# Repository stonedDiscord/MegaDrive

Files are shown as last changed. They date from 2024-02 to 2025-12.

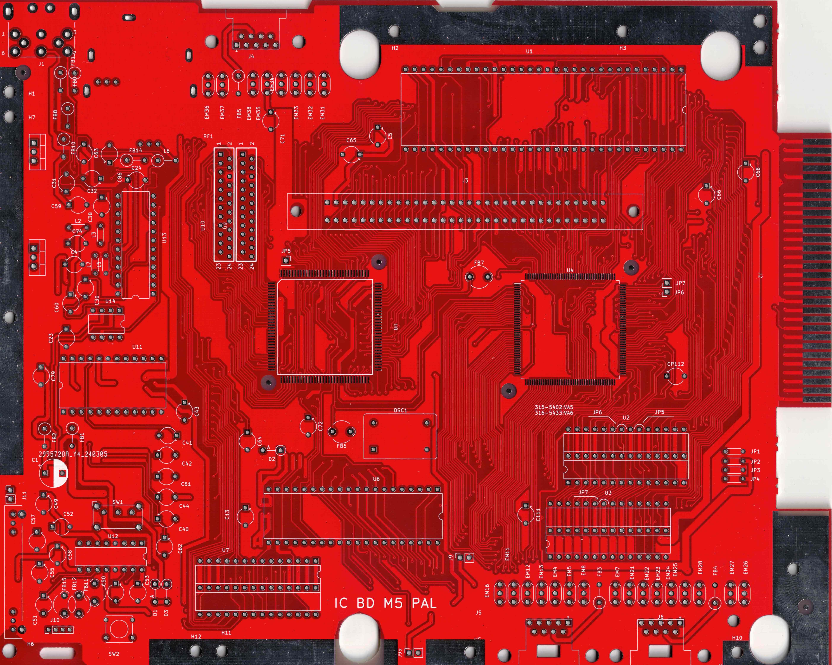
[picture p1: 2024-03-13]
scan.jpg

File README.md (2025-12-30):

# MegaDrive
An Open-Source HardWare (OSHW) recreation of the Sega Mega Drive

The design tries to be a 1:1 recreation of the original IC BD M5 PAL board.

## Some of the planned Changes and improvements
- [ ] Verify component values
- [ ] S-Video out

## Tips if you decide to make this/get it made
The dimensions are 240x191mm.

You will have to source the 2 SEGA custom chips from either a dead board or a chip dealer.

## Roadmap:
Look at the changes in the other revisions.

## Inspired by
https://github.com/Redherring32/OpenTendo

## Credits

ArcadeTV for the stripped scans:
https://circuit-board.de/forum/index.php/Thread/13913-STRIP-CLUB-PCB-Scans/

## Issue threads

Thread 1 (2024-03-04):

Holes

stonedDiscord, 2024-03-04:
I got this email from the board house

Hello,

Sorry to bother you, but there is an issue that we want to confirm with you before proceeding.

The drill holes and circles in KO layer are overlapped at the arrow in greber file, shall we proceed them as per drill layer or KO layer?

Looks like the cartridge port footprint is wrong, need to fix that.

danboid, 2025-09-05:
Hi @stonedDiscord

Did you get around to fixing that footprint?

stonedDiscord, 2025-09-05:
The board ended up being fine

stonedDiscord, 2025-09-05:
The issue was fixed in 286d83944ec59dee92658831e7c67fdc743904b5

Closed 2025-09-05.

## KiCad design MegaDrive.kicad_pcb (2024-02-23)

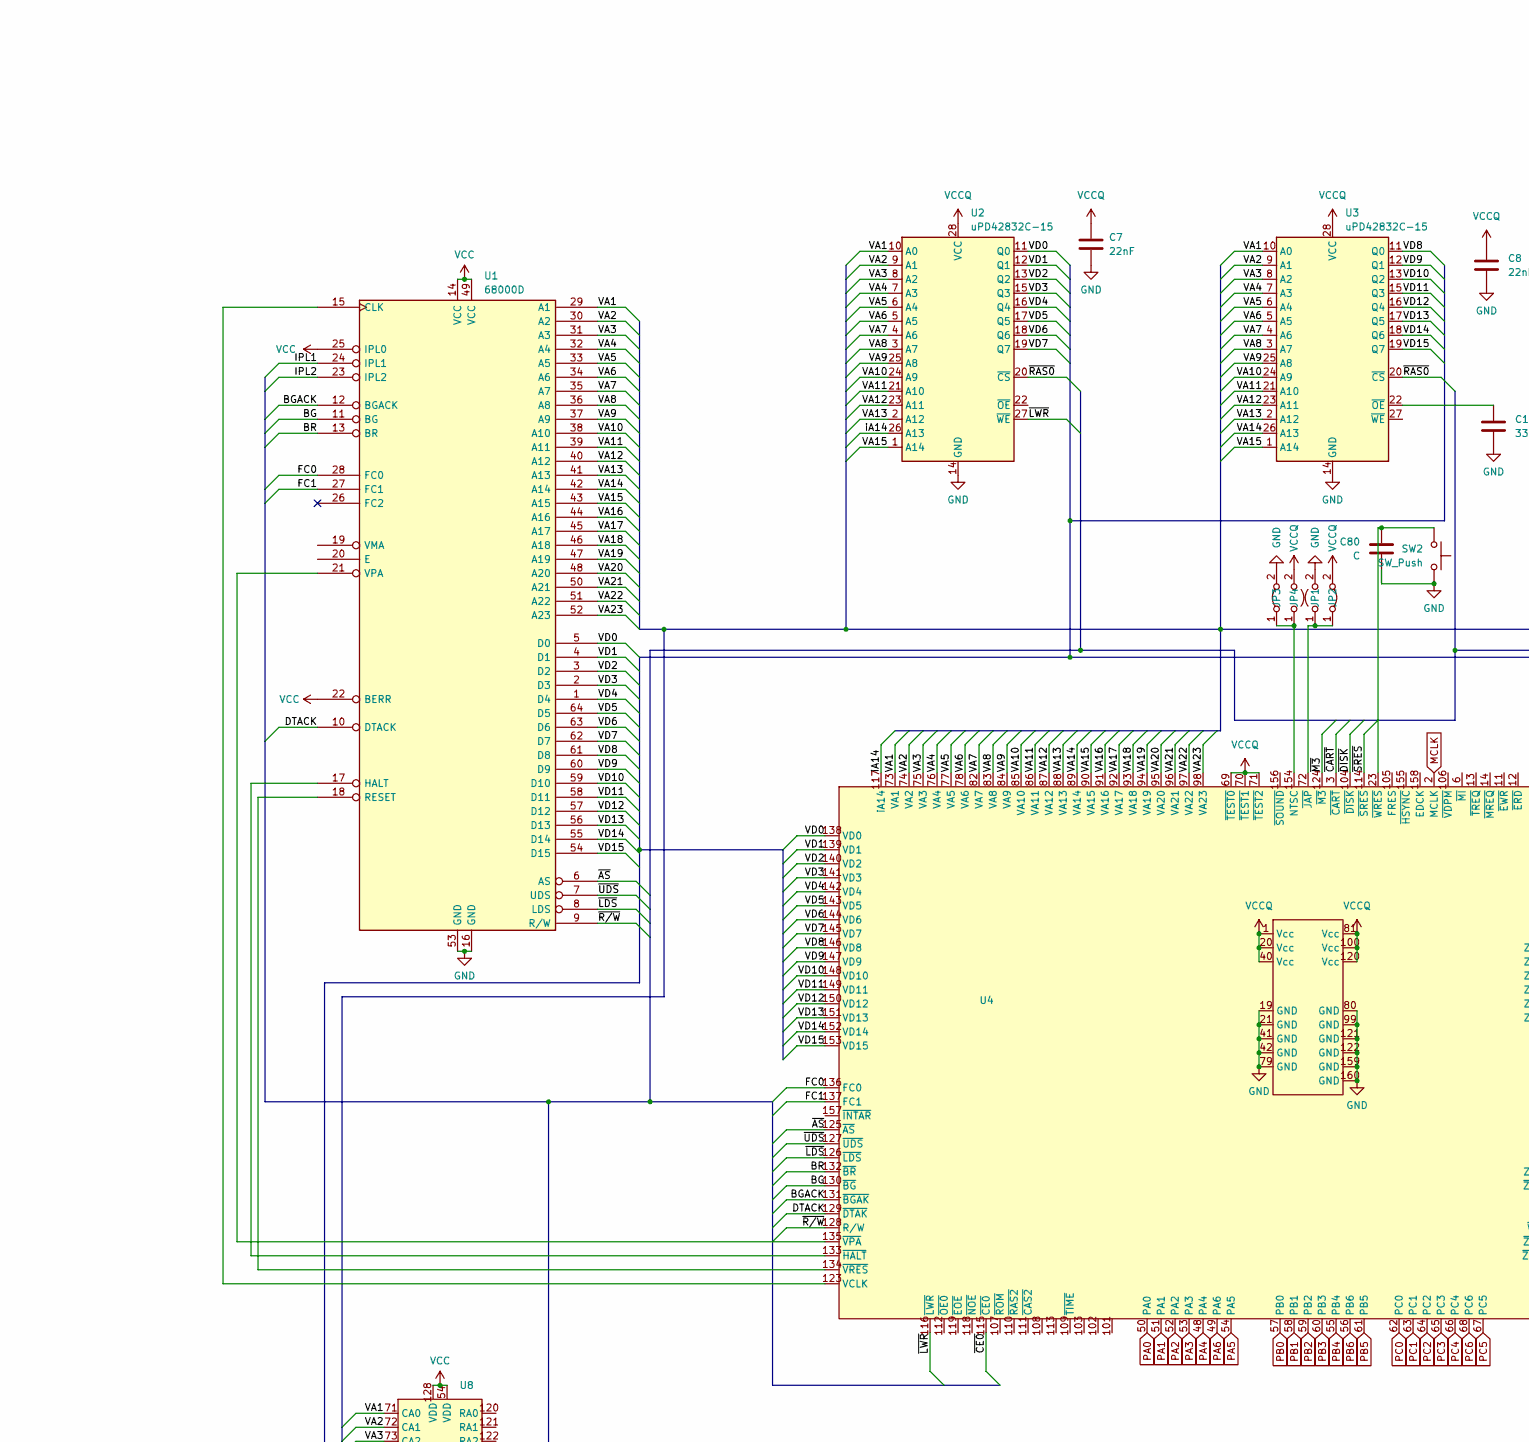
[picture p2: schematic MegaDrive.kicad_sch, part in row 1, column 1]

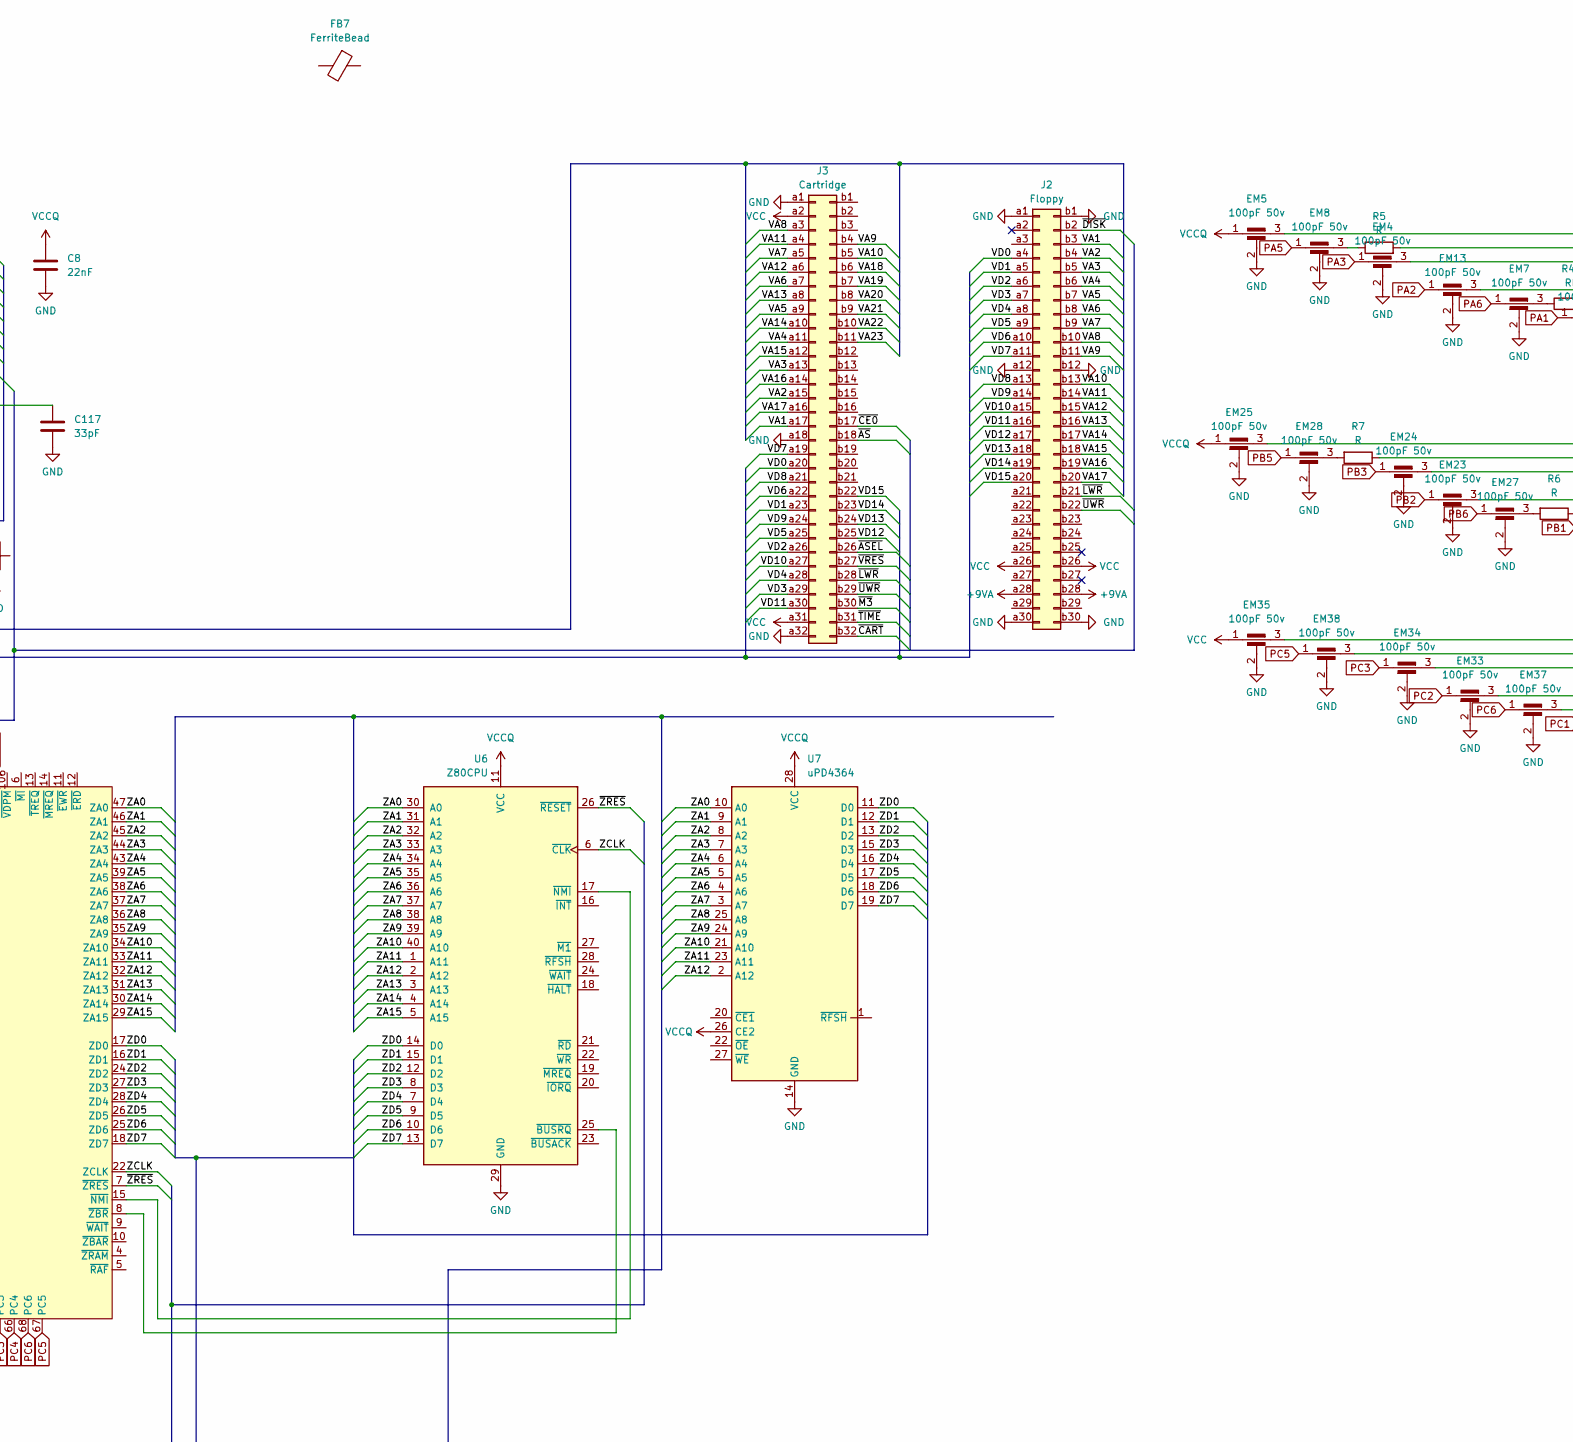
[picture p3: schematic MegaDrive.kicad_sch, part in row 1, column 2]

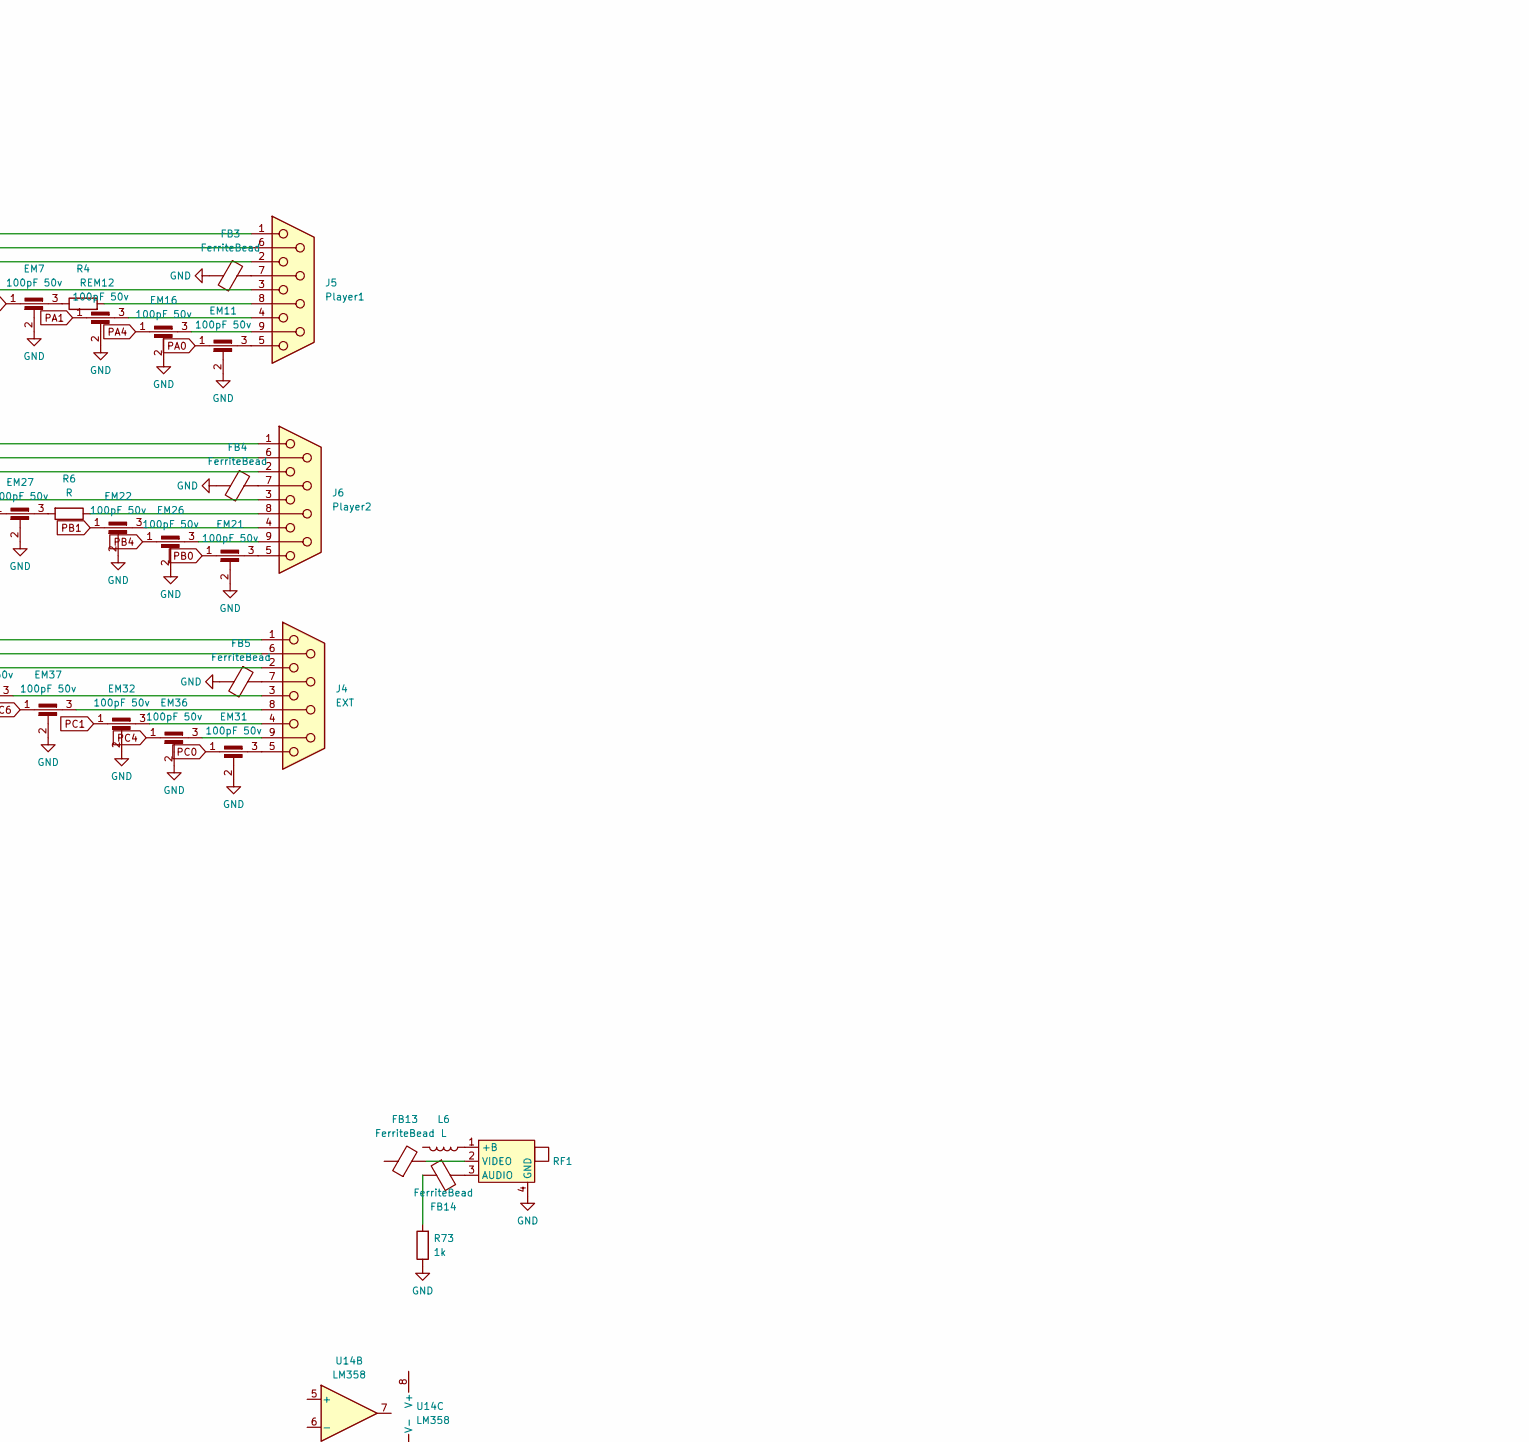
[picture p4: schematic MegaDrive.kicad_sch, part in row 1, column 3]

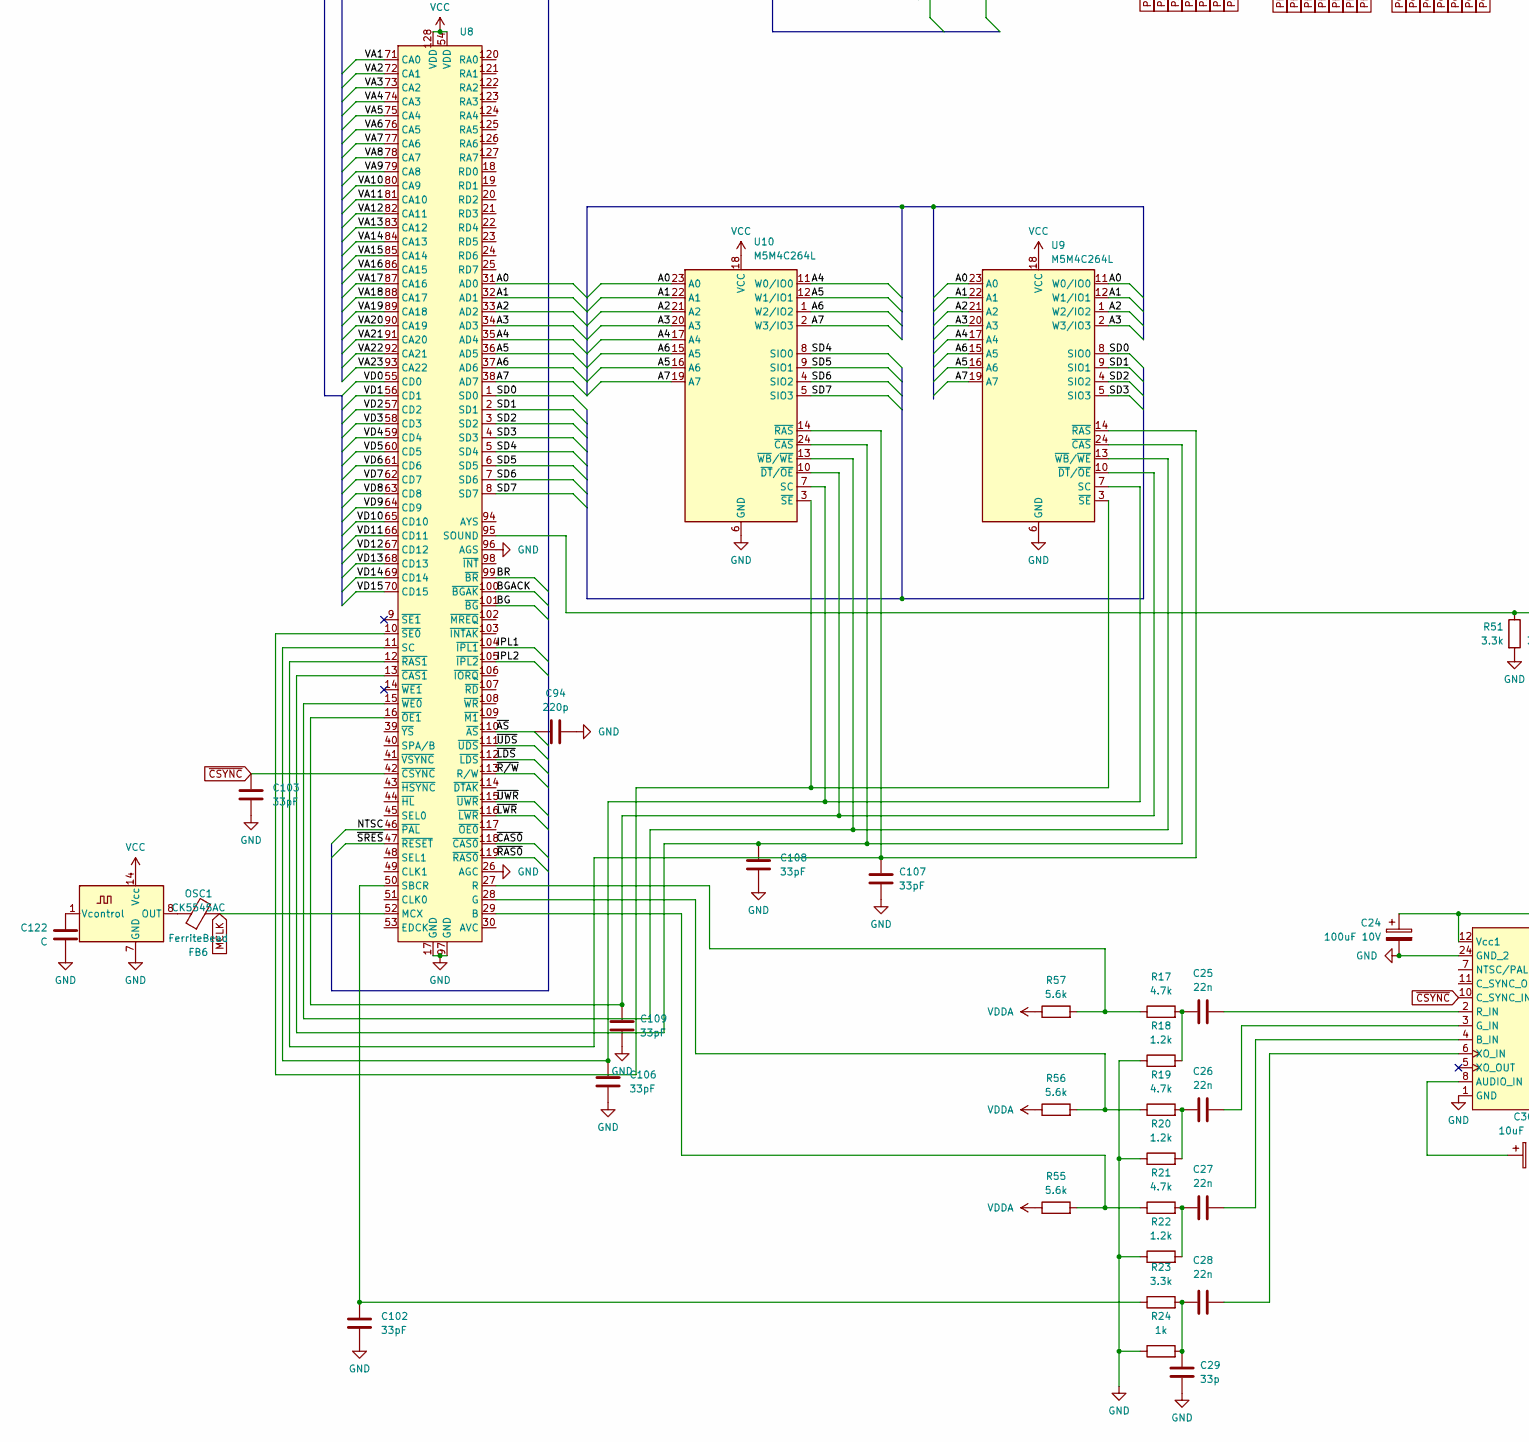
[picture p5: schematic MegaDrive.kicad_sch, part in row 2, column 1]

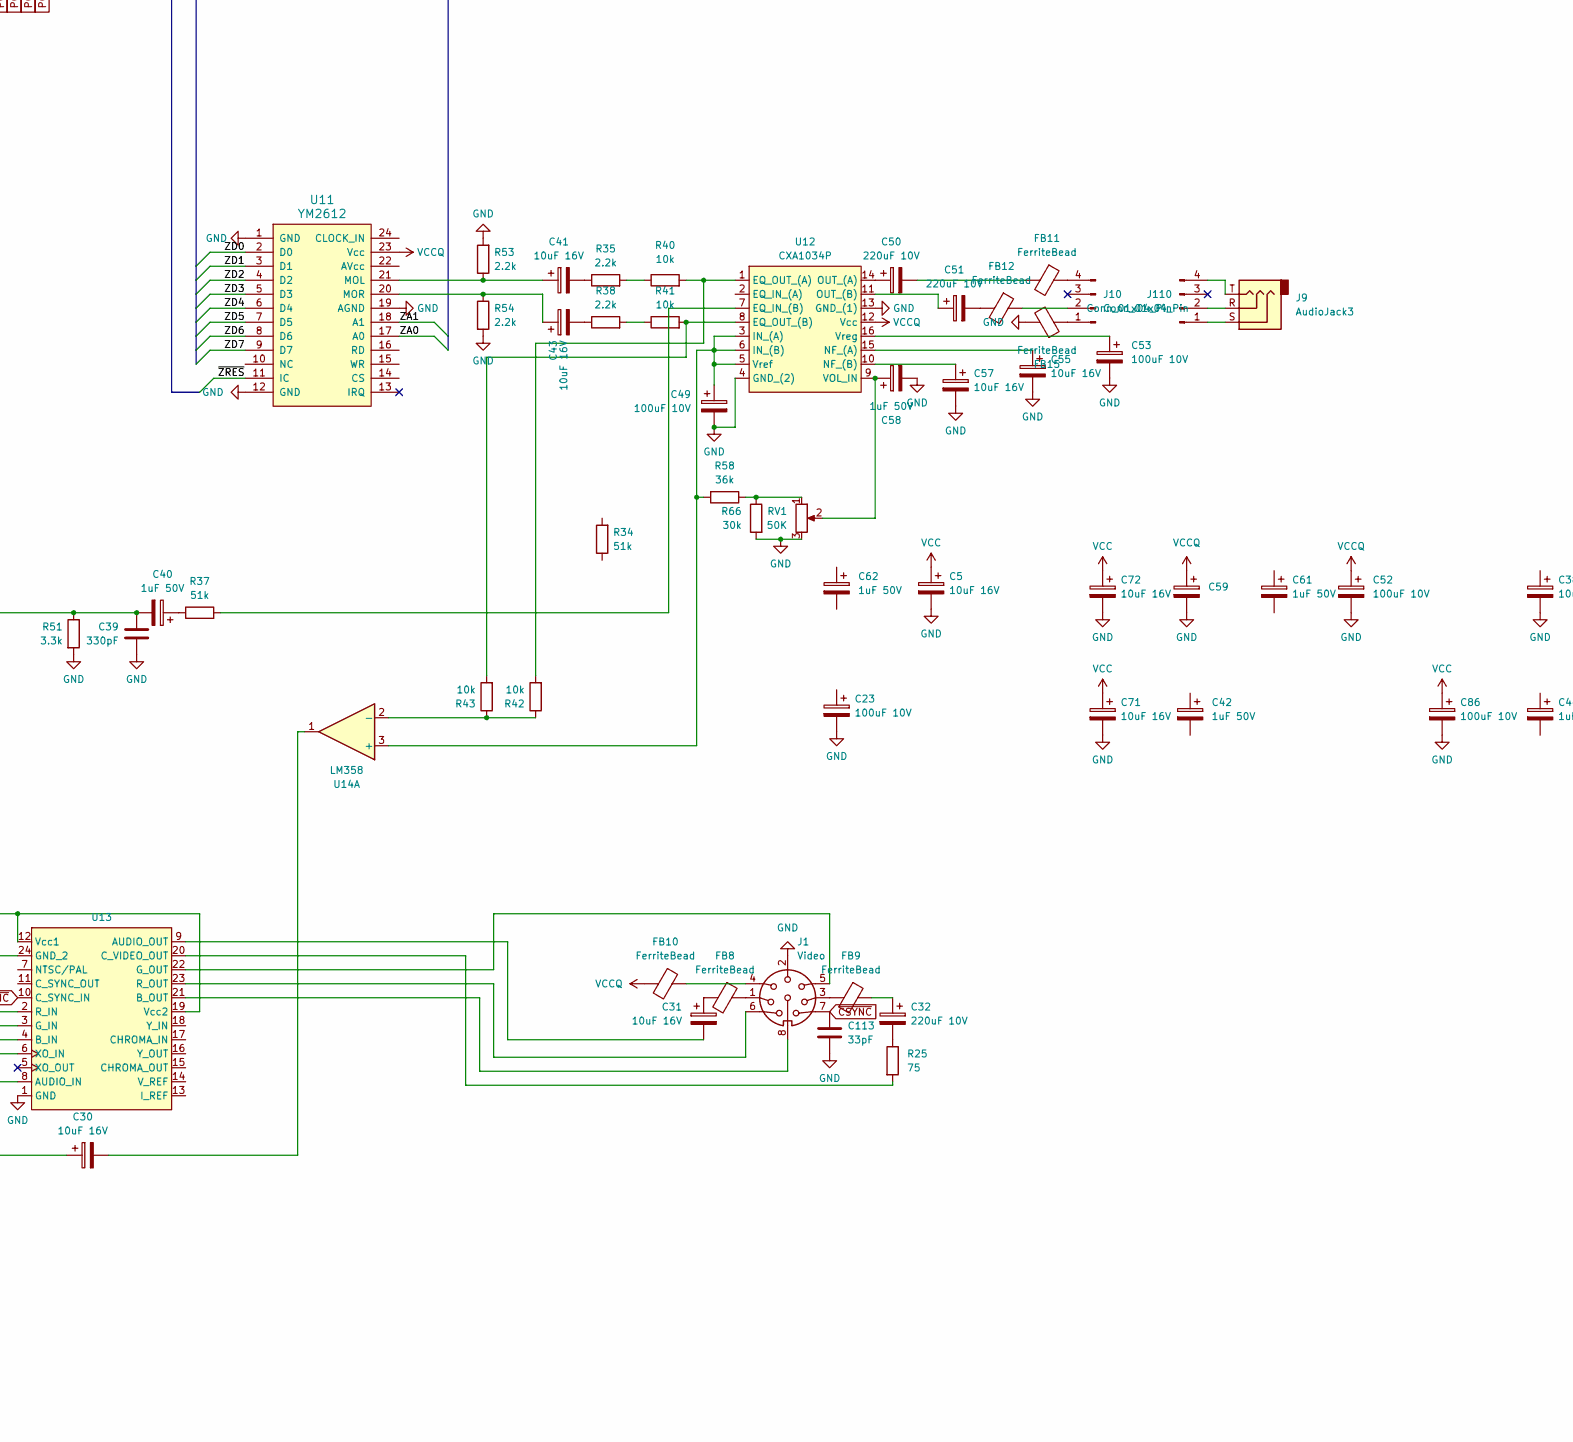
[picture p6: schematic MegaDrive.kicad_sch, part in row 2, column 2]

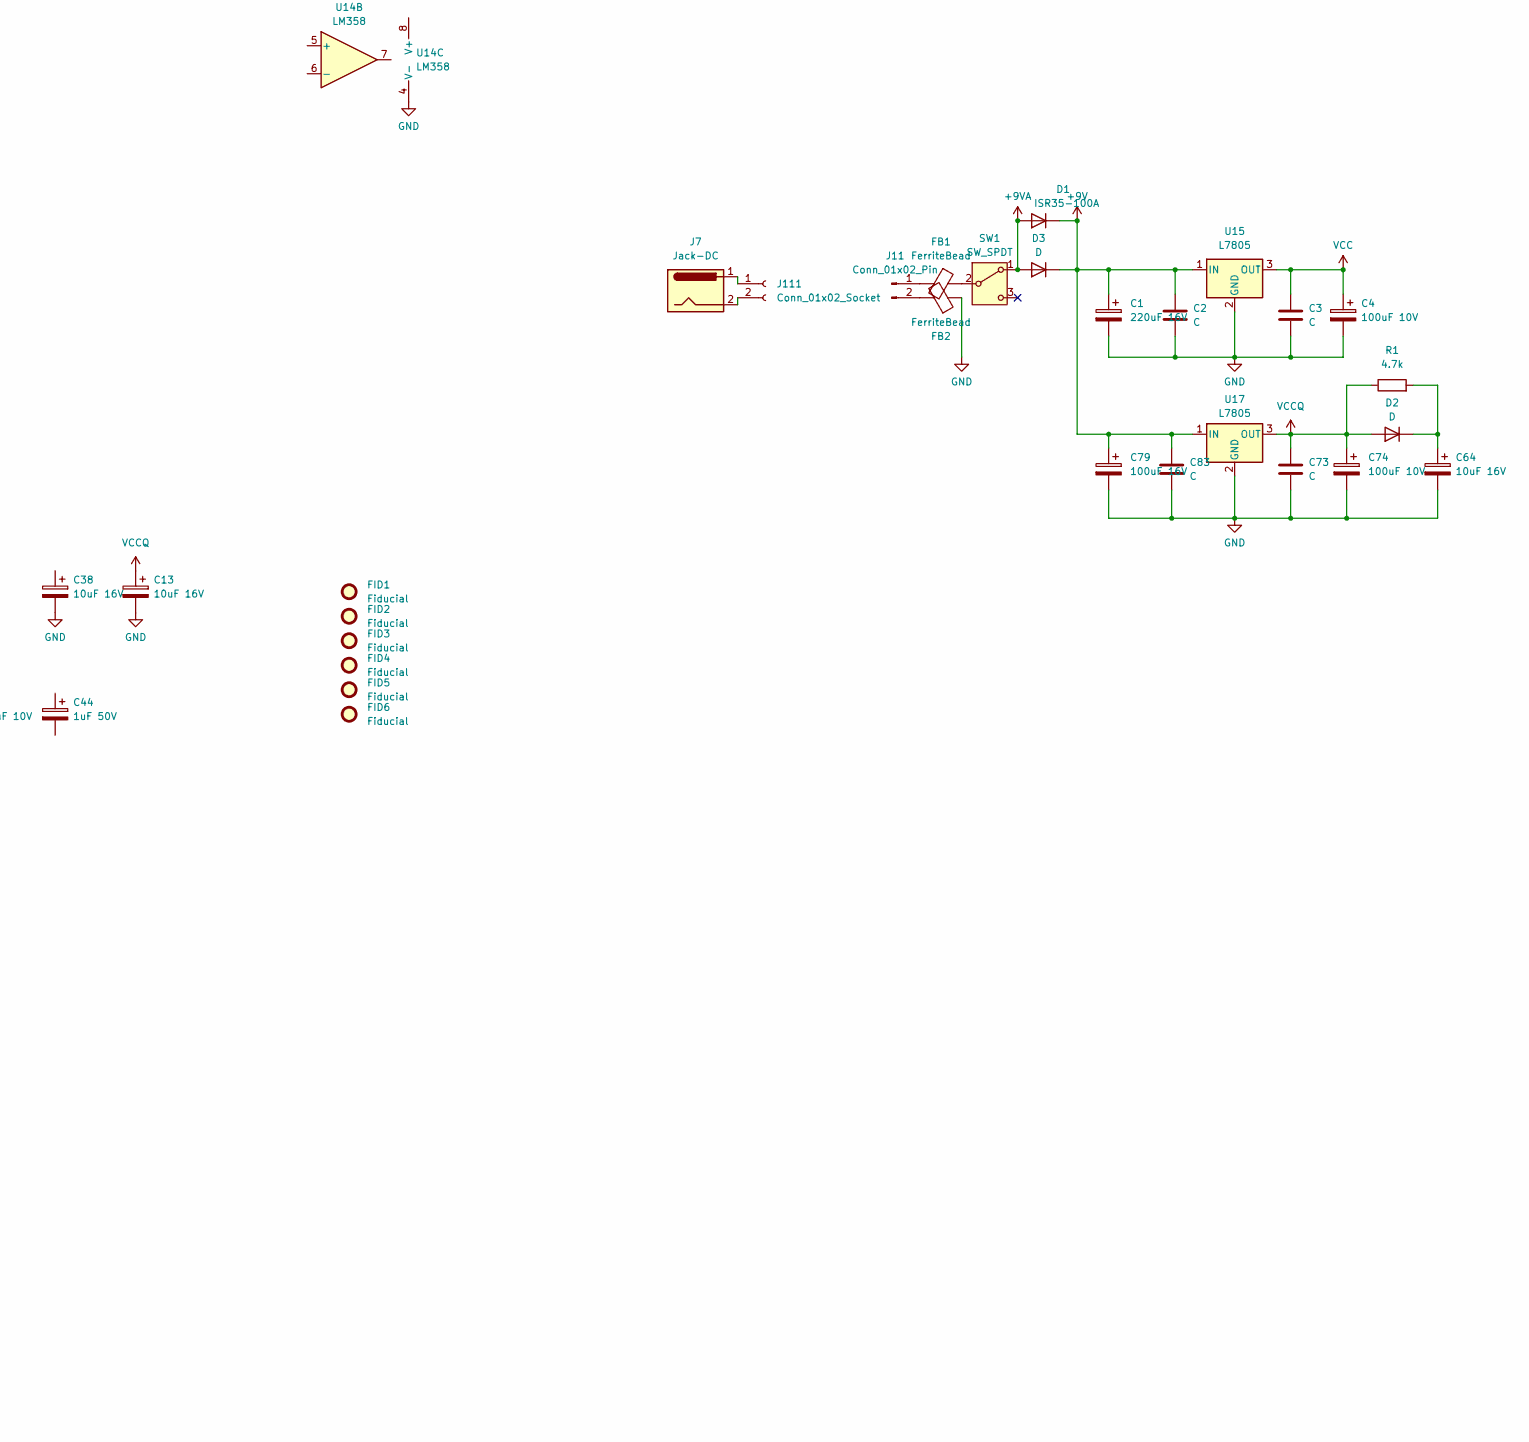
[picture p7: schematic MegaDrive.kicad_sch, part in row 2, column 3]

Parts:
C1: 220uF 16V; CP_Radial_D8.0mm_P5.00mm
C2, C3, C73, C80, C83, C122: C; C_0805_2012Metric
C4, C23, C24, C49, C52, C53: 100uF 10V; CP_Radial_Tantal_D4.5mm_P5.00mm
C5, C13, C30, C31, C38, C41, C43, C55, C57, C64, C71, C72: 10uF 16V; CP_Radial_Tantal_D4.5mm_P5.00mm
C7, C8: 22nF; C_0805_2012Metric
C25, C26, C27, C28: 22n; C_0805_2012Metric
C29: 33p; C_0805_2012Metric
C32, C50, C51: 220uF 10V; CP_Radial_Tantal_D4.5mm_P5.00mm
C39: 330pF; C_0805_2012Metric
C40, C42, C44, C58, C61, C62: 1uF 50V; CP_Radial_Tantal_D4.5mm_P5.00mm
C59: CP_Radial_Tantal_D4.5mm_P5.00mm
C74, C86: 100uF 10V; CP_Radial_D8.0mm_P5.00mm
C79: 100uF 16V; CP_Radial_D8.0mm_P5.00mm
C94: 220p; C_0805_2012Metric
C102, C103, C106, C107, C108, C109, C113, C117: 33pF; C_0805_2012Metric
D1: ISR35-100A; D_A-405_P5.08mm_Vertical_AnodeUp
D2, D3: D; D_A-405_P5.08mm_Vertical_AnodeUp
EM4, EM5, EM7, EM8, EM11, EM12, EM13, EM16, EM21, EM22, EM23, EM24, EM25, EM26, EM27, EM28, EM31, EM32, EM33, EM34, EM35, EM36, EM37, EM38: 100pF 50v; Resonator-3Pin_W6.0mm_H3.0mm
FB1, FB2, FB3, FB4, FB5, FB6, FB7, FB8, FB9, FB10, FB11, FB12, FB13, FB14, FB15: FerriteBead; LairdTech_28C0236-0JW-10
FID1, FID2, FID3, FID4, FID5, FID6: Fiducial; Fiducial_1.5mm_Mask4.5mm
J1: Video; DIN8Video
J2: Floppy; Expansion
J3: Cartridge; SEGA_2x32_Female_Vertical_THT
J4: EXT; DSUB-9_Female_Horizontal_P2.77x2.54mm_EdgePinOffset9.40mm
J5: Player1; DSUB-9_Female_Horizontal_P2.77x2.54mm_EdgePinOffset9.40mm
J6: Player2; DSUB-9_Female_Horizontal_P2.77x2.54mm_EdgePinOffset9.40mm
J7: Jack-DC; JWT_A3963_1x02_P3.96mm_Vertical
J9: AudioJack3; Jack_3.5mm_CUI_SJ1-3523N_Horizontal
J10, J110: Conn_01x04_Pin; PinHeader_1x04_P2.00mm_Vertical
J11: Conn_01x02_Pin; PinHeader_1x02_P2.54mm_Vertical
J111: Conn_01x02_Socket; PinHeader_1x02_P2.54mm_Vertical
JP1: JAP; R_Axial_DIN0204_L3.6mm_D1.6mm_P5.08mm_Horizontal
JP2: ENG; R_Axial_DIN0204_L3.6mm_D1.6mm_P5.08mm_Horizontal
JP3: PAL; R_Axial_DIN0204_L3.6mm_D1.6mm_P5.08mm_Horizontal
JP4: NTSC; R_Axial_DIN0204_L3.6mm_D1.6mm_P5.08mm_Horizontal
L6: L; L_Axial_L7.0mm_D3.3mm_P5.08mm_Vertical_Fastron_MICC
OSC1: CK5545AC; Oscillator_DIP-14
R1, R17, R19, R21: 4.7k; R_0805_2012Metric
R4, R5, R6, R7: R; R_0805_2012Metric
R18, R20, R22: 1.2k; R_0805_2012Metric
R23, R51: 3.3k; R_0805_2012Metric
R24, R73: 1k; R_0805_2012Metric
R25: 75; R_0805_2012Metric
R34, R37: 51k; R_0805_2012Metric
R35, R38, R53, R54: 2.2k; R_0805_2012Metric
R40, R41, R42, R43: 10k; R_0805_2012Metric
R55, R56, R57: 5.6k; R_0805_2012Metric
R58: 36k; R_0805_2012Metric
R66: 30k; R_0805_2012Metric
RF1: RFmod
RV1: 50K
SW1: SW_SPDT; SW_E-Switch_EG1224_SPDT_Angled
SW2: SW_Push; SW_Tactile_Straight_KSA0Axx1LFTR
U1: 68000D; DIP-64_W22.86mm
U2, U3: uPD42832C-15; DIP-28_DoubleLast
U4: PQFP-160_28x28mm_P0.65mm
U6: Z80CPU; DIP-40_W15.24mm
U7: uPD4364; DIP-28_DoubleFirst
U8: QFP128
U9, U10: M5M4C264L; ZIP-24
U11: YM2612; DIP-24_W15.24mm
U12: CXA1034P; DIP-16_W7.62mm
U13: DIP-24_W10.16mm
U14: LM358; DIP-8_W7.62mm
U15, U17: L7805; TO-220-3_Vertical

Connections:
+9V: C1.1, C2.1, C79.1, C83.1, D1.1 (K), D3.1 (K), U15.1 (IN), U17.1 (IN)
+9VA: D1.2 (A), D3.2 (A), J2.a28, J2.b28, SW1.1 (A)
/A0: U8.31 (AD0), U9.11 (W0/IO0), U9.23 (A0), U10.23 (A0)
/A1: U8.32 (AD1), U9.12 (W1/IO1), U9.22 (A1), U10.22 (A1)
/A2: U8.33 (AD2), U9.1 (W2/IO2), U9.21 (A2), U10.21 (A2)
/A3: U8.34 (AD3), U9.2 (W3/IO3), U9.20 (A3), U10.20 (A3)
/A4: U8.35 (AD4), U9.17 (A4), U10.11 (W0/IO0), U10.17 (A4)
/A5: U8.36 (AD5), U9.16 (A6), U10.12 (W1/IO1), U10.16 (A6)
/A6: U8.37 (AD6), U9.15 (A5), U10.1 (W2/IO2), U10.15 (A5)
/A7: U8.38 (AD7), U9.19 (A7), U10.2 (W3/IO3), U10.19 (A7)
/BG: U1.11 (BG), U4.130 (~BG), U8.101 (~BG)
/BGACK: U1.12 (BGACK), U4.131 (~BGAK), U8.100 (~BGAK)
/BR: U1.13 (BR), U4.132 (~BR), U8.99 (~BR)
/DTACK: U1.10 (DTACK), U4.129 (~DTAK)
/FC0: U1.28 (FC0), U4.136 (FC0)
/FC1: U1.27 (FC1), U4.137 (FC1)
/IPL1: U1.24 (IPL1), U8.104 (~IPL1)
/IPL2: U1.23 (IPL2), U8.105 (~IPL2)
/NTSC: U8.46 (~PAL)
/SD0: U8.1 (SD0), U9.8 (SIO0)
/SD1: U8.2 (SD1), U9.9 (SIO1)
/SD2: U8.3 (SD2), U9.4 (SIO2)
/SD3: U8.4 (SD3), U9.5 (SIO3)
/SD4: U8.5 (SD4), U10.8 (SIO0)
/SD5: U8.6 (SD5), U10.9 (SIO1)
/SD6: U8.7 (SD6), U10.4 (SIO2)
/SD7: U8.8 (SD7), U10.5 (SIO3)
/VA1: J2.b3, J3.a17, U1.29 (A1), U2.10 (A0), U3.10 (A0), U4.73 (VA1), U8.71 (CA0)
/VA2: J2.b4, J3.a15, U1.30 (A2), U2.9 (A1), U3.9 (A1), U4.74 (VA2), U8.72 (CA1)
/VA3: J2.b5, J3.a13, U1.31 (A3), U2.8 (A2), U3.8 (A2), U4.75 (VA3), U8.73 (CA2)
/VA4: J2.b6, J3.a11, U1.32 (A4), U2.7 (A3), U3.7 (A3), U4.76 (VA4), U8.74 (CA3)
/VA5: J2.b7, J3.a9, U1.33 (A5), U2.6 (A4), U3.6 (A4), U4.77 (VA5), U8.75 (CA4)
/VA6: J2.b8, J3.a7, U1.34 (A6), U2.5 (A5), U3.5 (A5), U4.78 (VA6), U8.76 (CA5)
/VA7: J2.b9, J3.a5, U1.35 (A7), U2.4 (A6), U3.4 (A6), U4.82 (VA7), U8.77 (CA6)
/VA8: J2.b10, J3.a3, U1.36 (A8), U2.3 (A7), U3.3 (A7), U4.83 (VA8), U8.78 (CA7)
/VA9: J2.b11, J3.b4, U1.37 (A9), U2.25 (A8), U3.25 (A8), U4.84 (VA9), U8.79 (CA8)
/VA10: J2.b13, J3.b5, U1.38 (A10), U2.24 (A9), U3.24 (A9), U4.85 (VA10), U8.80 (CA9)
/VA11: J2.b14, J3.a4, U1.39 (A11), U2.21 (A10), U3.21 (A10), U4.86 (VA11), U8.81 (CA10)
/VA12: J2.b15, J3.a6, U1.40 (A12), U2.23 (A11), U3.23 (A11), U4.87 (VA12), U8.82 (CA11)
/VA13: J2.b16, J3.a8, U1.41 (A13), U2.2 (A12), U3.2 (A12), U4.88 (VA13), U8.83 (CA12)
/VA14: J2.b17, J3.a10, U1.42 (A14), U3.26 (A13), U4.89 (VA14), U8.84 (CA13)
/VA15: J2.b18, J3.a12, U1.43 (A15), U2.1 (A14), U3.1 (A14), U4.90 (VA15), U8.85 (CA14)
/VA16: J2.b19, J3.a14, U1.44 (A16), U4.91 (VA16), U8.86 (CA15)
/VA17: J2.b20, J3.a16, U1.45 (A17), U4.92 (VA17), U8.87 (CA16)
/VA18: J3.b6, U1.46 (A18), U4.93 (VA18), U8.88 (CA17)
/VA19: J3.b7, U1.47 (A19), U4.94 (VA19), U8.89 (CA18)
/VA20: J3.b8, U1.48 (A20), U4.95 (VA20), U8.90 (CA19)
/VA21: J3.b9, U1.50 (A21), U4.96 (VA21), U8.91 (CA20)
/VA22: J3.b10, U1.51 (A22), U4.97 (VA22), U8.92 (CA21)
/VA23: J3.b11, U1.52 (A23), U4.98 (VA23), U8.93 (CA22)
/VD0: J2.a4, J3.a20, U1.5 (D0), U2.11 (Q0), U4.138 (VD0), U8.55 (CD0)
/VD1: J2.a5, J3.a23, U1.4 (D1), U2.12 (Q1), U4.139 (VD1), U8.56 (CD1)
/VD2: J2.a6, J3.a26, U1.3 (D2), U2.13 (Q2), U4.140 (VD2), U8.57 (CD2)
/VD3: J2.a7, J3.a29, U1.2 (D3), U2.15 (Q3), U4.141 (VD3), U8.58 (CD3)
/VD4: J2.a8, J3.a28, U1.1 (D4), U2.16 (Q4), U4.142 (VD4), U8.59 (CD4)
/VD5: J2.a9, J3.a25, U1.64 (D5), U2.17 (Q5), U4.143 (VD5), U8.60 (CD5)
/VD6: J2.a10, J3.a22, U1.63 (D6), U2.18 (Q6), U4.144 (VD6), U8.61 (CD6)
/VD7: J2.a11, J3.a19, U1.62 (D7), U2.19 (Q7), U4.145 (VD7), U8.62 (CD7)
/VD8: J2.a13, J3.a21, U1.61 (D8), U3.11 (Q0), U4.146 (VD8), U8.63 (CD8)
/VD9: J2.a14, J3.a24, U1.60 (D9), U3.12 (Q1), U4.147 (VD9), U8.64 (CD9)
/VD10: J2.a15, J3.a27, U1.59 (D10), U3.13 (Q2), U4.148 (VD10), U8.65 (CD10)
/VD11: J2.a16, J3.a30, U1.58 (D11), U3.15 (Q3), U4.149 (VD11), U8.66 (CD11)
/VD12: J2.a17, J3.b25, U1.57 (D12), U3.16 (Q4), U4.150 (VD12), U8.67 (CD12)
/VD13: J2.a18, J3.b24, U1.56 (D13), U3.17 (Q5), U4.151 (VD13), U8.68 (CD13)
/VD14: J2.a19, J3.b23, U1.55 (D14), U3.18 (Q6), U4.152 (VD14), U8.69 (CD14)
/VD15: J2.a20, J3.b22, U1.54 (D15), U3.19 (Q7), U4.153 (VD15), U8.70 (CD15)
/ZA0: U4.47 (ZA0), U6.30 (A0), U7.10 (A0), U11.17 (A0)
/ZA1: U4.46 (ZA1), U6.31 (A1), U7.9 (A1), U11.18 (A1)
/ZA2: U4.45 (ZA2), U6.32 (A2), U7.8 (A2)
/ZA3: U4.44 (ZA3), U6.33 (A3), U7.7 (A3)
/ZA4: U4.43 (ZA4), U6.34 (A4), U7.6 (A4)
/ZA5: U4.39 (ZA5), U6.35 (A5), U7.5 (A5)
/ZA6: U4.38 (ZA6), U6.36 (A6), U7.4 (A6)
/ZA7: U4.37 (ZA7), U6.37 (A7), U7.3 (A7)
/ZA8: U4.36 (ZA8), U6.38 (A8), U7.25 (A8)
/ZA9: U4.35 (ZA9), U6.39 (A9), U7.24 (A9)
/ZA10: U4.34 (ZA10), U6.40 (A10), U7.21 (A10)
/ZA11: U4.33 (ZA11), U6.1 (A11), U7.23 (A11)
/ZA12: U4.32 (ZA12), U6.2 (A12), U7.2 (A12)
/ZA13: U4.31 (ZA13), U6.3 (A13)
/ZA14: U4.30 (ZA14), U6.4 (A14)
/ZA15: U4.29 (ZA15), U6.5 (A15)
/ZCLK: U4.22 (ZCLK), U6.6 (~CLK)
/ZD0: U4.17 (ZD0), U6.14 (D0), U7.11 (D0), U11.2 (D0)
/ZD1: U4.16 (ZD1), U6.15 (D1), U7.12 (D1), U11.3 (D1)
/ZD2: U4.24 (ZD2), U6.12 (D2), U7.13 (D2), U11.4 (D2)
/ZD3: U4.27 (ZD3), U6.8 (D3), U7.15 (D3), U11.5 (D3)
/ZD4: U4.28 (ZD4), U6.7 (D4), U7.16 (D4), U11.6 (D4)
/ZD5: U4.26 (ZD5), U6.9 (D5), U7.17 (D5), U11.7 (D5)
/ZD6: U4.25 (ZD6), U6.10 (D6), U7.18 (D6), U11.8 (D6)
/ZD7: U4.18 (ZD7), U6.13 (D7), U7.19 (D7), U11.9 (D7)
/iA14: U2.26 (A13), U4.117 (iA14)
/~ASEL: J3.b26
/~AS: C94.2, J3.b18, U1.6 (AS), U4.125 (~AS), U8.110 (~AS)
/~CART: J3.b32, U4.3 (~CART)
/~CAS0: U8.118 (~CAS0)
/~CE0: J3.b17, U4.115 (~CE0)
/~DISK: J2.b2, U4.104 (~DISK)
/~LDS: U1.8 (LDS), U4.126 (~LDS), U8.112 (~LDS)
/~LWR: J2.b21, J3.b28, U2.27 (~WE), U4.116 (~LWR), U8.116 (~LWR)
/~M3: J3.b30, U4.124 (~M3)
/~RAS0: U2.20 (~CS), U3.20 (~CS), U8.119 (~RAS0)
/~R/W: U1.9 (R/W), U4.128 (R/W), U8.113 (R/W)
/~SRES: U4.114 (~SRES), U8.47 (~RESET)
/~TIME: J3.b31
/~UDS: U1.7 (UDS), U4.127 (~UDS), U8.111 (~UDS)
/~UWR: J2.b22, J3.b29, U8.115 (~UWR)
/~VRES: J3.b27
/~ZRES: U4.7 (~ZRES), U6.26 (~RESET), U11.11 (IC)
GND: C1.2, C2.2, C3.2, C4.2, C5.2, C7.2, C8.2, C13.2, C23.2, C24.2, C29.2, C38.2, C39.2, C49.2, C52.2, C53.2, C55.2, C57.2, C58.2, C59.2, C64.2, C71.2, C72.2, C73.2, C74.2, C79.2, C80.2, C83.2, C86.2, C94.1, C102.2, C103.2, C106.2, C107.2, C108.2, C109.2, C113.2, C117.2, C122.2, EM4.2, EM5.2, EM7.2, EM8.2, EM11.2, EM12.2, EM13.2, EM16.2, EM21.2, EM22.2, EM23.2, EM24.2, EM25.2, EM26.2, EM27.2, EM28.2, EM31.2, EM32.2, EM33.2, EM34.2, EM35.2, EM36.2, EM37.2, EM38.2, FB2.1, FB3.2, FB4.2, FB5.2, FB15.2, J1.2, J2.a1, J2.a12, J2.a30, J2.b1, J2.b12, J2.b30, J3.a1, J3.a18, J3.a32, JP1.2 (B), JP3.2 (B), OSC1.7 (GND), R18.1, R20.1, R22.1, R24.1, R51.2, R53.2, R54.2, R66.2, R73.1, RF1.4 (GND), RV1.3, SW2.1, U1.16 (GND), U1.53 (GND), U2.14 (GND), U3.14 (GND), U4.19 (GND), U4.21 (GND), U4.41 (GND), U4.42 (GND), U4.79 (GND), U4.80 (GND), U4.99 (GND), U4.121 (GND), U4.122 (GND), U4.159 (GND), U4.160 (GND), U6.29 (GND), U7.14 (GND), U8.17 (GND), U8.26 (AGC), U8.96 (AGS), U8.97 (GND), U9.6 (GND), U10.6 (GND), U11.1 (GND), U11.12 (GND), U11.19 (AGND), U12.4 (GND_(2)), U12.13 (GND_(1)), U13.1 (GND), U13.24 (GND_2), U14.4 (V-), U15.2 (GND), U17.2 (GND)
MCLK: FB6.2, U4.2 (MCLK), U8.52 (MCX)
unnamed: C25.1, R17.2, R18.2
unnamed: C26.1, R19.2, R20.2
unnamed: C27.1, R21.2, R22.2
unnamed: C28.2, C29.1, R23.2, R24.2
unnamed: C30.2, U14.1
unnamed: C31.1, FB8.2
unnamed: C32.1, FB9.1
unnamed: C32.2, R25.1
unnamed: C40.1, R37.1
unnamed: C41.2, R35.1
unnamed: C43.2, R38.1
unnamed: C50.2, FB11.2
unnamed: C51.2, FB12.2
unnamed: C64.1, D2.1 (K), R1.2
unnamed: EM4.3, J5.2
unnamed: EM5.3, J5.1
unnamed: EM7.3, R4.1
unnamed: EM8.3, R5.1
unnamed: EM11.3, J5.5
unnamed: EM12.3, J5.4
unnamed: EM13.3, J5.3
unnamed: EM16.3, J5.9
unnamed: EM21.3, J6.5
unnamed: EM22.3, J6.4
unnamed: EM23.3, J6.3
unnamed: EM24.3, J6.2
unnamed: EM25.3, J6.1
unnamed: EM26.3, J6.9
unnamed: EM27.3, R6.2
unnamed: EM28.3, R7.2
unnamed: EM31.3, J4.5
unnamed: EM32.3, J4.4
unnamed: EM33.3, J4.3
unnamed: EM34.3, J4.2
unnamed: EM35.3, J4.1
unnamed: EM36.3, J4.9
unnamed: EM37.3, J4.8
unnamed: EM38.3, J4.6
unnamed: FB3.1, J5.7
unnamed: FB4.1, J6.7
unnamed: FB5.1, J4.7
unnamed: FB8.1, J1.1
unnamed: FB9.2, J1.3
unnamed: FB10.1, J1.4
unnamed: FB14.1, R73.2
unnamed: J5.6, R5.2
unnamed: J5.8, R4.2
unnamed: J6.6, R7.1
unnamed: J6.8, R6.1
unnamed: FB15.1, J10.1
unnamed: FB12.1, J10.2
unnamed: FB11.1, J10.4
unnamed: FB1.2, J11.1
unnamed: FB2.2, J11.2
unnamed: J9.S, J110.1
unnamed: J9.R, J110.2
unnamed: J9.T, J110.4
unnamed: J7.1, J111.1
unnamed: J7.2, J111.2
unnamed: JP1.1 (A), JP2.1 (A), U4.72 (~JAP)
unnamed: JP3.1 (A), JP4.1 (A), U4.154 (NTSC)
unnamed: FB6.1, OSC1.8 (OUT)
unnamed: C122.1, OSC1.1 (Vcontrol)
unnamed: R35.2, R40.1
unnamed: R38.2, R41.1
unnamed: R58.1, R66.1, RV1.1
unnamed: L6.2, RF1.1 (+B)
unnamed: FB14.2, RF1.3 (AUDIO)
unnamed: FB13.2, RF1.2 (VIDEO)
unnamed: FB1.1, SW1.2 (B)
unnamed: U1.15 (CLK), U4.123 (VCLK)
unnamed: U1.17 (HALT), U4.133 (~HALT)
unnamed: U1.18 (RESET), U4.134 (~VRES)
unnamed: U1.21 (VPA), U4.135 (~VPA)
unnamed: C117.1, U3.22 (~OE)
unnamed: U4.15 (~NMI), U6.17 (~NMI)
unnamed: C80.1, SW2.2, U4.23 (~WRES)
unnamed: U4.8 (~ZBR), U6.25 (~BUSRQ)
unnamed: R21.1, R55.2, U8.29 (B)
unnamed: R19.1, R56.2, U8.28 (G)
unnamed: R17.1, R57.2, U8.27 (R)
unnamed: C102.1, R23.1, U8.50 (SBCR)
unnamed: C39.1, C40.2, R51.1, U8.95 (SOUND)
unnamed: C106.1, U8.11 (SC), U9.7 (SC), U10.7 (SC)
unnamed: C108.1, U8.13 (~CAS1), U9.24 (~CAS), U10.24 (~CAS)
unnamed: C109.1, U8.16 (~OE1), U9.10 (~DT/~OE), U10.10 (~DT/~OE)
unnamed: C107.1, U8.12 (~RAS1), U9.14 (~RAS), U10.14 (~RAS)
unnamed: U8.10 (~SE0), U9.3 (~SE), U10.3 (~SE)
unnamed: U8.15 (~WE0), U9.13 (~WB/~WE), U10.13 (~WB/~WE)
unnamed: C41.1, R53.1, U11.21 (MOL)
unnamed: C43.1, R54.1, U11.20 (MOR)
unnamed: R37.2, U12.7 (EQ_IN_(B))
unnamed: R40.2, R42.2, U12.1 (EQ_OUT_(A))
unnamed: R41.2, R43.2, U12.8 (EQ_OUT_(B))
unnamed: C49.1, R58.2, U12.3 (IN_(A)), U12.5 (Vref), U12.6 (IN_(B)), U14.3 (+)
unnamed: C55.1, U12.15 (NF_(A))
unnamed: C57.1, U12.10 (NF_(B))
unnamed: C50.1, U12.14 (OUT_(A))
unnamed: C51.1, U12.11 (OUT_(B))
unnamed: C58.1, RV1.2, U12.9 (VOL_IN)
unnamed: C53.1, U12.16 (Vreg)
unnamed: C30.1, U13.8 (AUDIO_IN)
unnamed: C31.2, U13.9 (AUDIO_OUT)
unnamed: C27.2, U13.4 (B_IN)
unnamed: J1.8, U13.21 (B_OUT)
unnamed: R25.2, U13.20 (C_VIDEO_OUT)
unnamed: C26.2, U13.3 (G_IN)
unnamed: J1.5, U13.22 (G_OUT)
unnamed: C25.2, U13.2 (R_IN)
unnamed: J1.6, U13.23 (R_OUT)
unnamed: C24.1, U13.12 (Vcc1), U13.19 (Vcc2)
unnamed: C28.1, U13.6 (XO_IN)
unnamed: R42.1, R43.1, U14.2 (-)
PA0: EM11.1, U4.50 (PA0)
PA1: EM12.1, U4.51 (PA1)
PA2: EM13.1, U4.52 (PA2)
PA3: EM4.1, U4.53 (PA3)
PA4: EM16.1, U4.48 (PA4)
PA5: EM8.1, U4.54 (PA5)
PA6: EM7.1, U4.49 (PA6)
PB0: EM21.1, U4.57 (PB0)
PB1: EM22.1, U4.58 (PB1)
PB2: EM23.1, U4.59 (PB2)
PB3: EM24.1, U4.60 (PB3)
PB4: EM26.1, U4.55 (PB4)
PB5: EM28.1, U4.61 (PB5)
PB6: EM27.1, U4.56 (PB6)
PC0: EM31.1, U4.62 (PC0)
PC1: EM32.1, U4.63 (PC1)
PC2: EM33.1, U4.64 (PC2)
PC3: EM34.1, U4.65 (PC3)
PC4: EM36.1, U4.66 (PC4)
PC5: EM38.1, U4.67 (PC5)
PC6: EM37.1, U4.68 (PC6)
VCC: C3.1, C4.1, C5.1, C71.1, C72.1, C86.1, EM35.1, J2.a26, J2.b26, J3.a2, J3.a31, OSC1.14 (Vcc), U1.14 (VCC), U1.22 (BERR), U1.25 (IPL0), U1.49 (VCC), U8.54 (VDD), U8.128 (VDD), U9.18 (VCC), U10.18 (VCC), U15.3 (OUT)
VCCQ: C7.1, C8.1, C13.1, C52.1, C59.1, C73.1, C74.1, D2.2 (A), EM5.1, EM25.1, FB10.2, JP2.2 (B), JP4.2 (B), R1.1, U2.28 (VCC), U3.28 (VCC), U4.1 (Vcc), U4.20 (Vcc), U4.40 (Vcc), U4.69 (~TEST0), U4.70 (~TEST1), U4.71 (~TEST2), U4.81 (Vcc), U4.100 (Vcc), U4.120 (Vcc), U6.11 (VCC), U7.26 (CE2), U7.28 (VCC), U11.23 (Vcc), U12.12 (Vcc), U17.3 (OUT)
VDDA: R55.1, R56.1, R57.1
~CSYNC: C103.1, C113.1, J1.7, U8.42 (~CSYNC), U13.10 (C_SYNC_IN)

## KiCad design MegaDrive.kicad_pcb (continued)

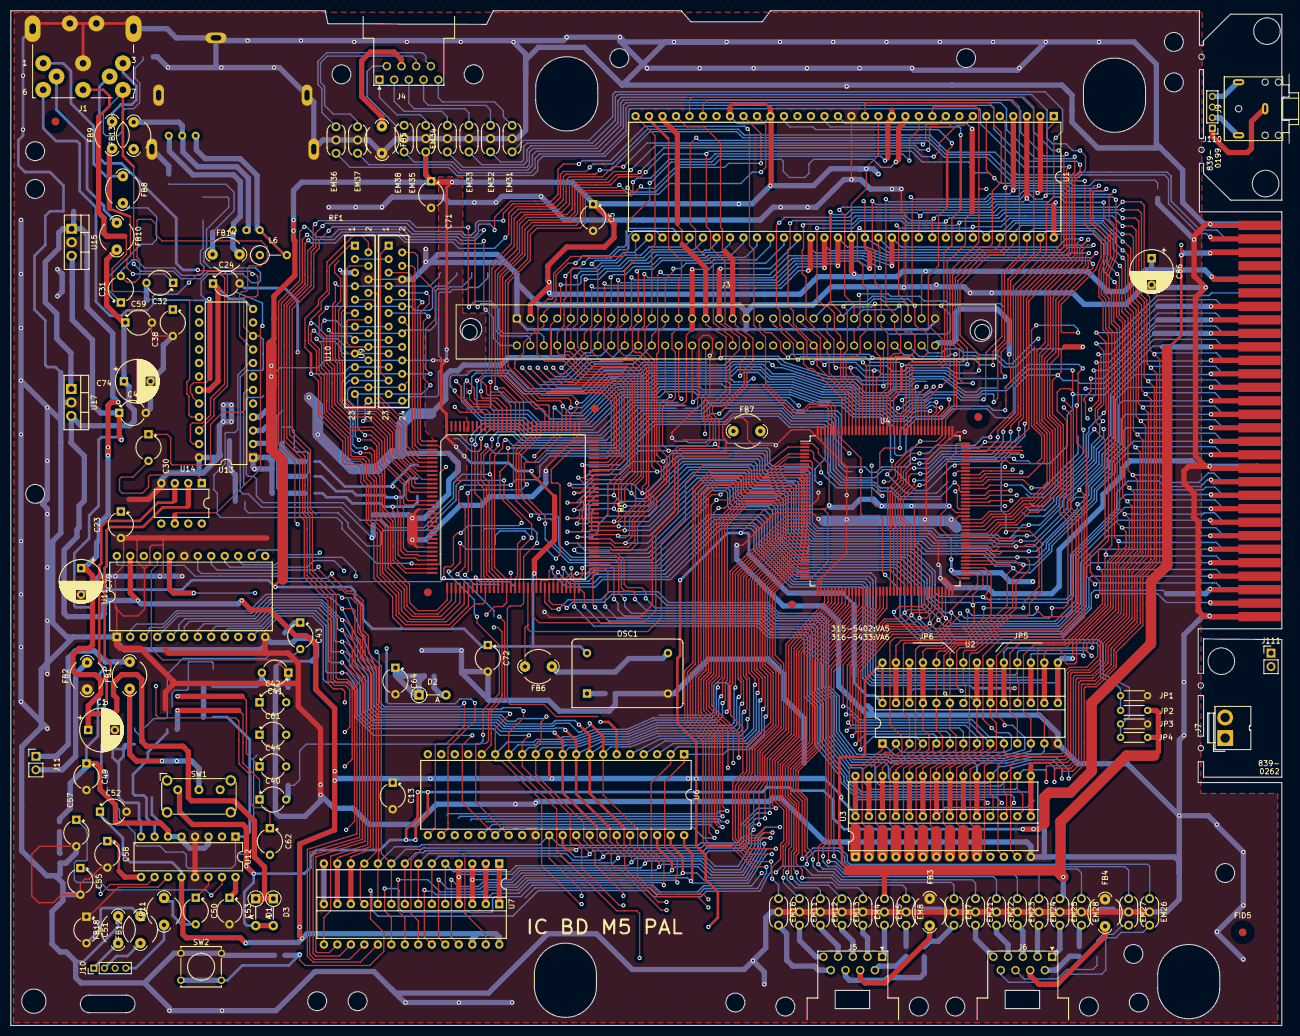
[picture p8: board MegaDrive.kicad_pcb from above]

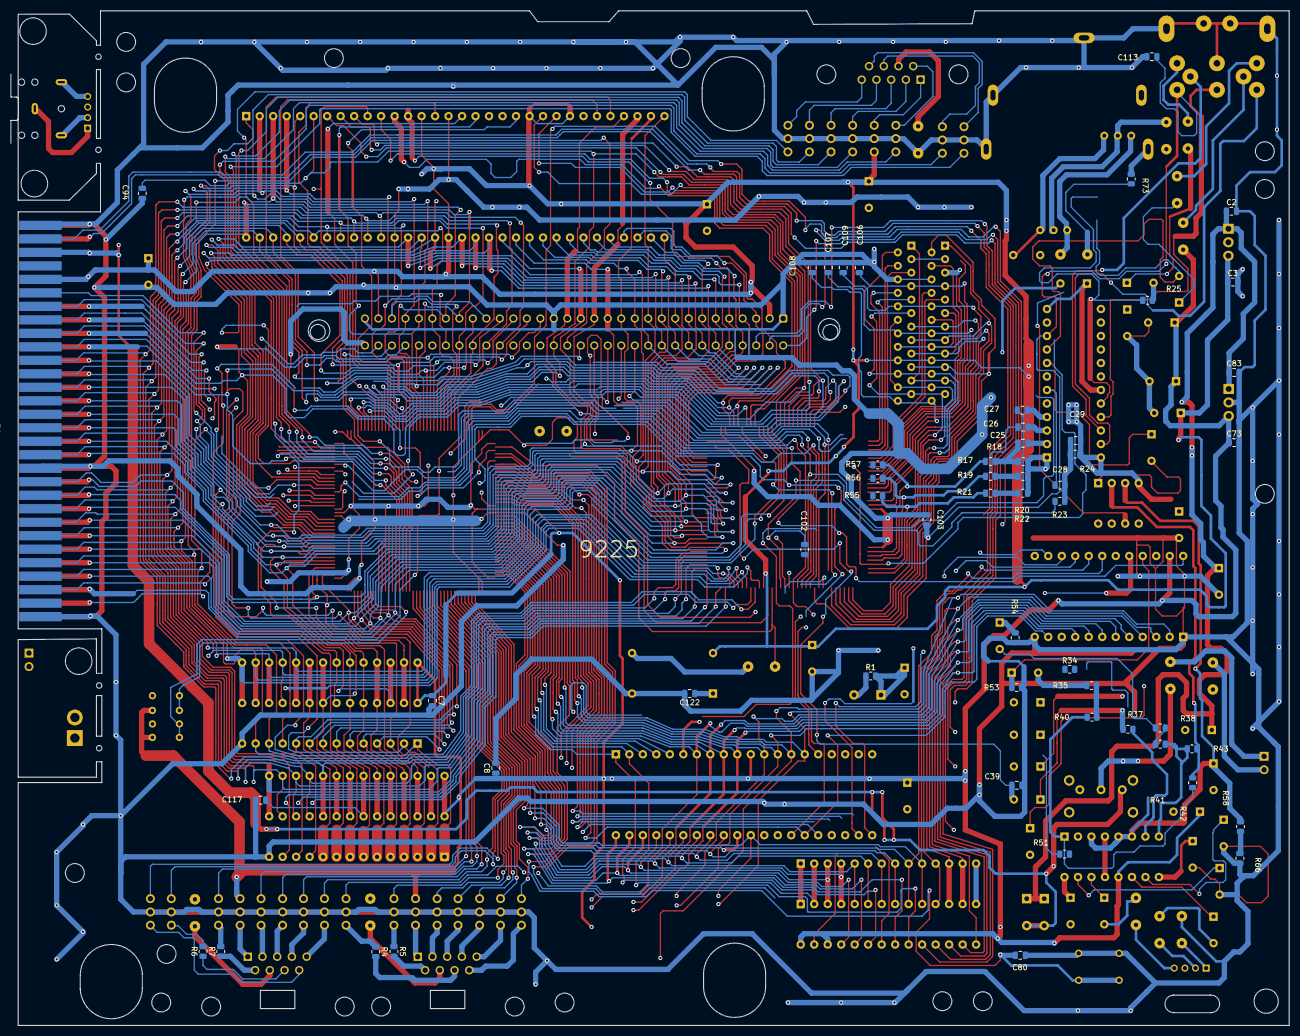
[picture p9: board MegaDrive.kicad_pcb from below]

Board: 2 copper layers, 240.6 x 191.0 mm, 170 parts (55 on the bottom side), 244 nets.

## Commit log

2024-03-03 pour on the audio board
    [MegaDrive.kicad_sch]
2024-03-05 fix hole overlap
2024-03-13 use D-sub connctors that can be ordered
    [MegaDrive.kicad_sch]
2024-03-14 missing resistor and bom fixup
    [MegaDrive.kicad_sch]
2024-03-20 fix some cap values and probably mess some up
    [MegaDrive.kicad_sch]
2024-03-22 add silkscreen so no one else rotates their vdp
    [MegaDrive.kicad_sch]
2025-05-02 do not try this footprint trick
2025-12-30 larger qfp footprint
2025-12-30 missing zclk connection
    [MegaDrive.kicad_sch]
2025-12-30 cant recommend getting this done by a board house
